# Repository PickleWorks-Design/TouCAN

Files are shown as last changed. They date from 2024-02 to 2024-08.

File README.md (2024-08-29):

# TouCAN
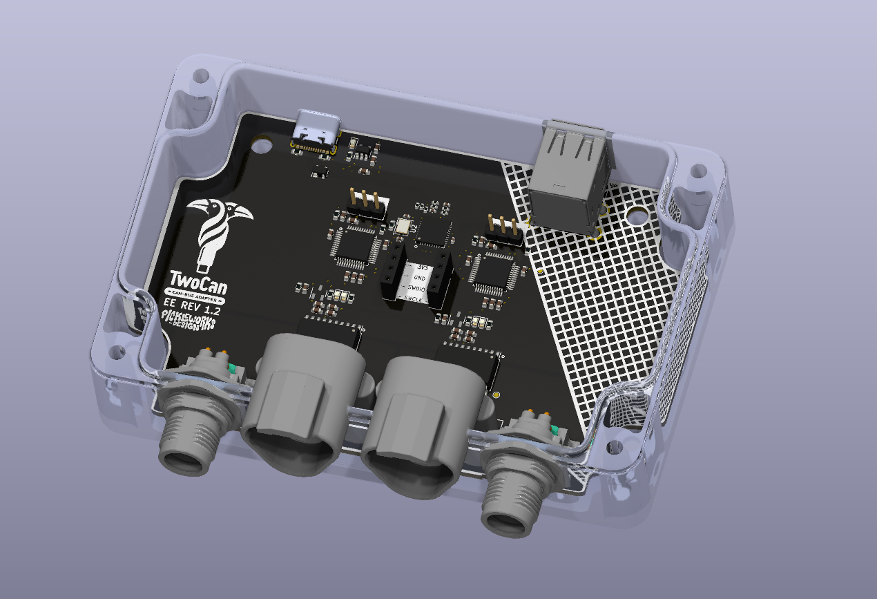
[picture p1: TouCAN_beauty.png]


Personal Project To integrate 2 Can Adapters in 1 board with Deutch DT 3pin connectors and an onboard usb HUB

USB to Can Adapter

This Project is Based on the CANAble USB to Canbus adapter project https://github.com/makerbase-mks/CANable-MKS/tree/main/Hardware/MKS%20CANable%20V2.0

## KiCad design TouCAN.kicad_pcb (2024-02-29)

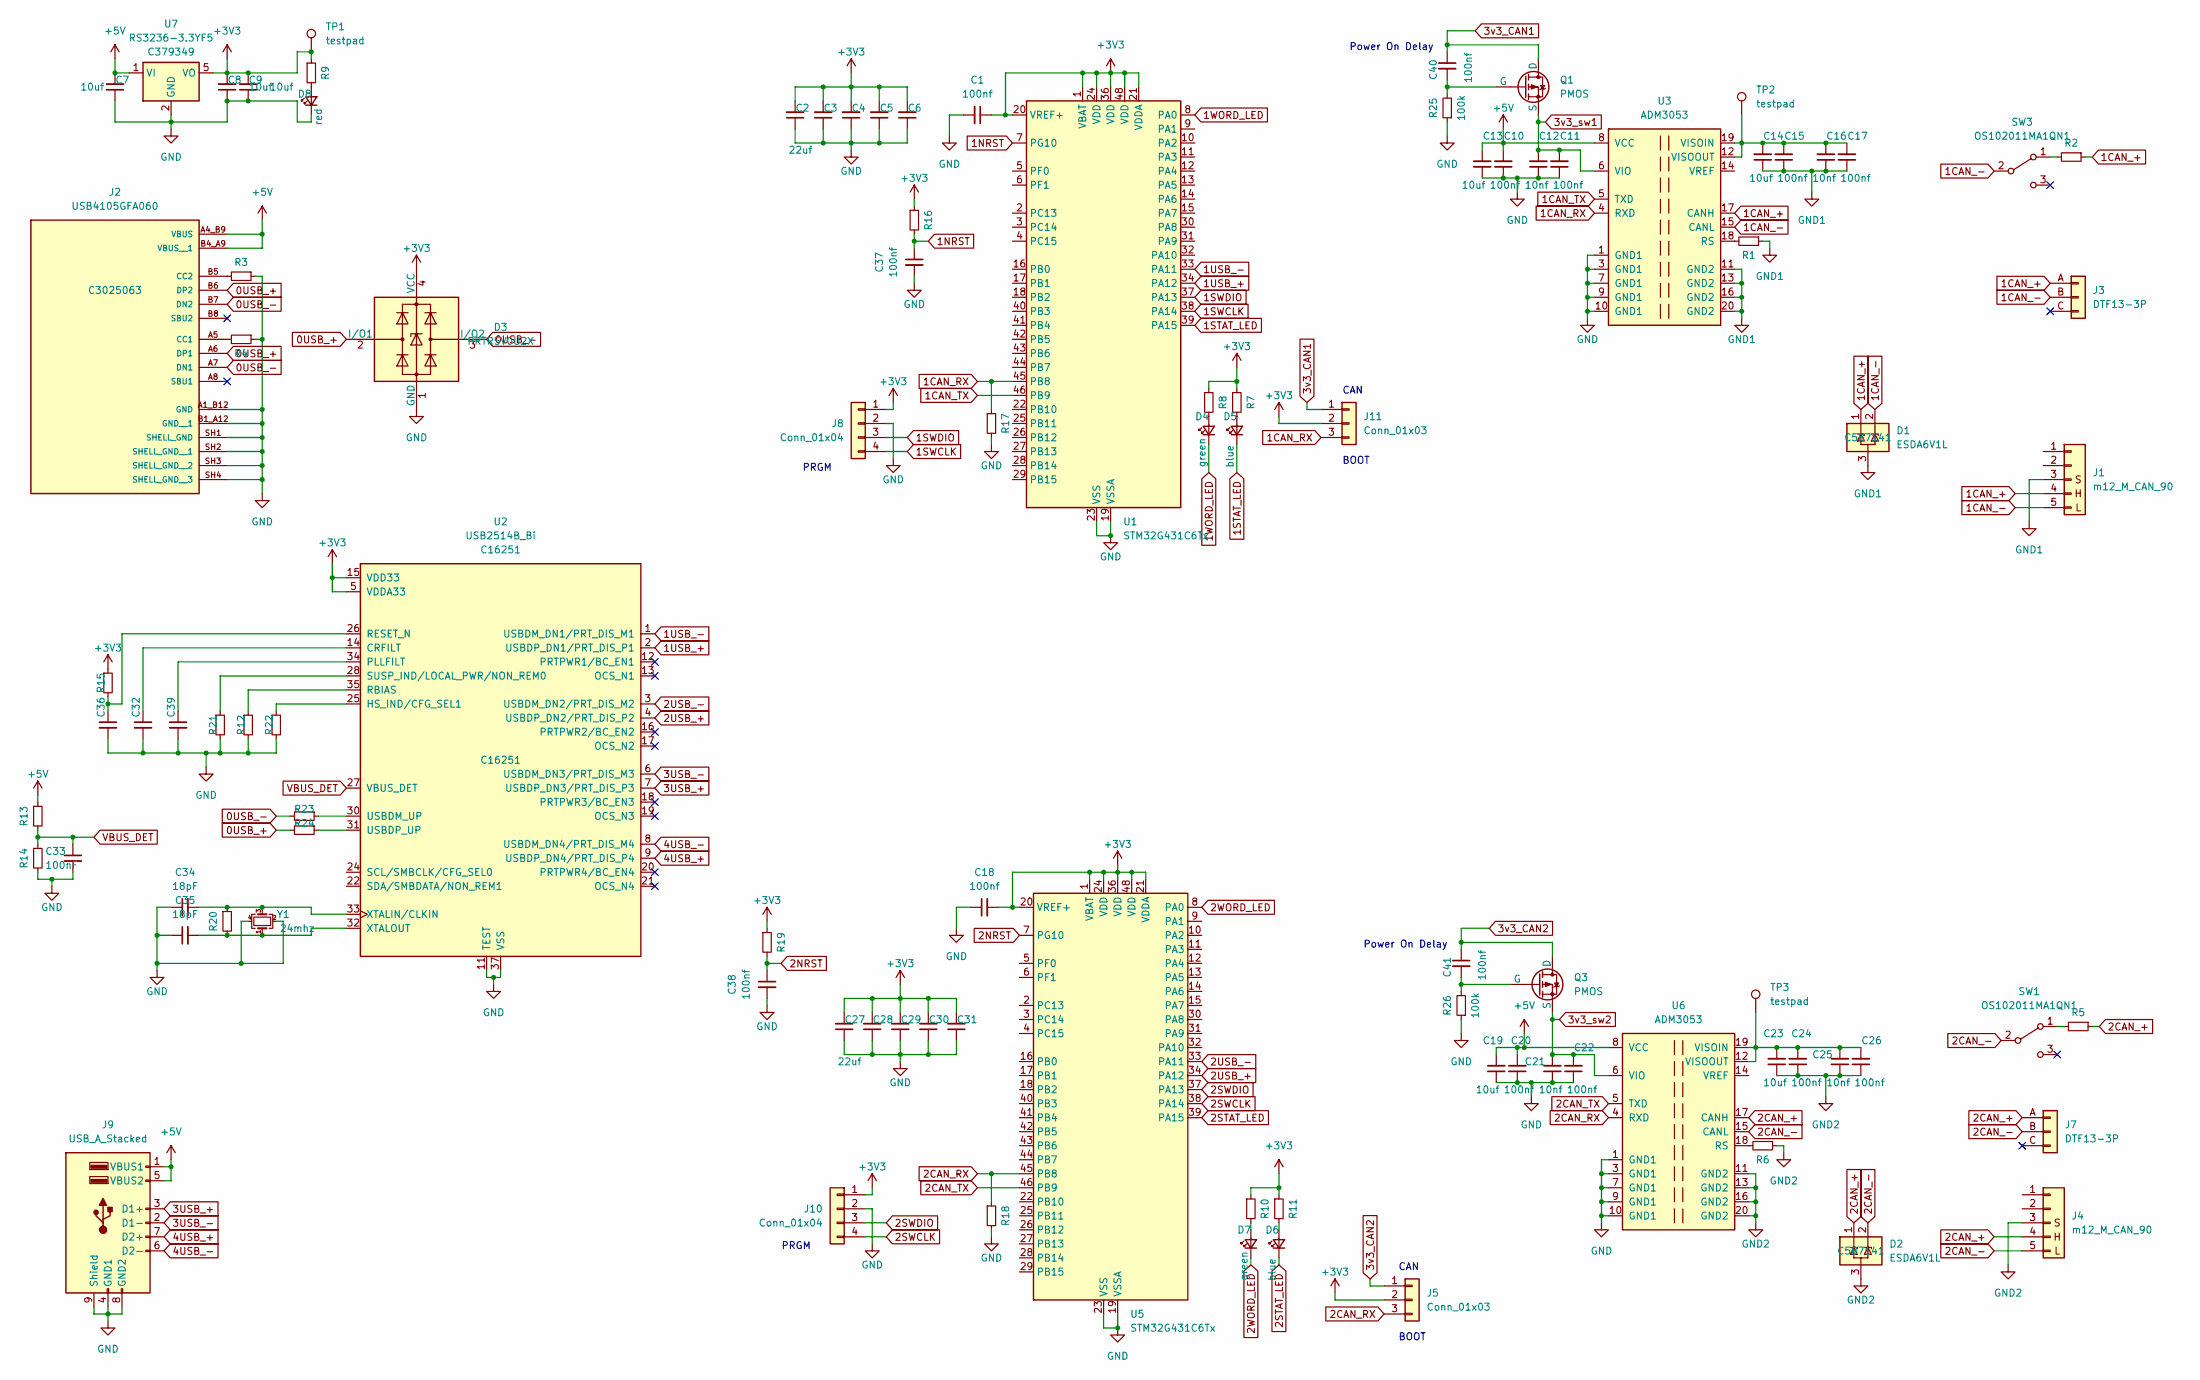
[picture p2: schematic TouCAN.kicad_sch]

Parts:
C1, C10, C11, C15, C17, C18, C20, C22, C24, C26, C37, C38, C40, C41: 100nf; C_0603_1608Metric; LCSC C14663
C2, C3, C4, C5, C6, C27, C28, C29, C30, C31: 22uf; C_0603_1608Metric; LCSC C59461
C7, C8, C9, C13, C14, C19, C23: 10uf; C_0603_1608Metric; LCSC C96446
C12, C16, C21, C25: 10nf; C_0603_1608Metric; LCSC C57112
C32, C33, C36, C39: 100nF; C_0402_1005Metric; LCSC C1525
C34, C35: 18pF; C_0402_1005Metric; LCSC C1549
D1, D2: ESDA6V1L; SOT-23-3; LCSC C587141
D3: PRTR5V0U2X; SOT-143; LCSC C2827688
D4, D7: green; LED_0603_1608Metric; LCSC C72043
D5, D6: blue; LED_0603_1608Metric; LCSC C72041
D8: red; LED_0603_1608Metric; LCSC C72044
J1, J4: m12_M_CAN_90; M12A-05PMMR-EE0001
J2: USB4105GFA060; GCT_USB4105GFA060; PARTREV B3; LCSC C3025063
J3, J7: DTF13-3P
J5, J11: Conn_01x03; PinHeader_1x03_P2.54mm_Vertical
J8, J10: Conn_01x04; PinSocket_1x04_P2.54mm_Vertical; LCSC C2691448
J9: USB_A_Stacked; USB_A_CUI_UJ2-ADH-TH_Horizontal_Stacked
Q1, Q3: PMOS; PMV48XP
R1, R6: 10r; R_0603_1608Metric; LCSC C22859
R2, R5: 120r; R_0603_1608Metric; LCSC C22787
R3, R4: 5.1k; R_0603_1608Metric; LCSC C23186
R7, R8, R9, R10, R11: 1k; R_0603_1608Metric; LCSC C21190
R12: 12k; R_0402_1005Metric; LCSC C25752
R13, R14, R15, R21, R22: 100k; R_0402_1005Metric; LCSC C25741
R16, R17, R18, R19: 10k; R_0603_1608Metric; LCSC C25804
R20: 1M; R_0603_1608Metric; LCSC C3152128
R23, R24: 0R; R_0402_1005Metric; LCSC C25086
R25, R26: 100k; R_0603_1608Metric; LCSC C25803
SW1, SW3: OS102011MA1QN1; LCSC C226259
TP1, TP2, TP3: testpad; TestPoint_Pad_D1.0mm
U1, U5: STM32G431C6Tx; LQFP-48_7x7mm_P0.5mm; LCSC C730096
U2: USB2514B_Bi; QFN-36-1EP_6x6mm_P0.5mm_EP3.7x3.7mm; LCSC C16251
U3, U6: ADM3053; SOIC-20W_7.5x12.8mm_P1.27mm; LCSC C117821
U7: RS3236-3.3YF5; SOT-23-5; LCSC C379349
Y1: 24mhz; Crystal_SMD_3225-4Pin_3.2x2.5mm; LCSC C362370

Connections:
0USB_+: D3.2 (I/O1), J2.A6 (DP1), J2.B6 (DP2), R24.2
0USB_-: D3.3 (I/O2), J2.A7 (DN1), J2.B7 (DN2), R23.2
1CAN_+: D1.1 (IO1), J1.4, J3.A (Pin_1), R2.1, U3.17 (CANH)
1CAN_-: D1.2 (IO2), J1.5, J3.B (Pin_2), SW3.2 (B), U3.15 (CANL)
1CAN_RX: J11.3, R17.1, U1.45 (PB8), U3.4 (RXD)
1CAN_TX: U1.46 (PB9), U3.5 (TXD)
1NRST: C37.1, R16.2, U1.7 (PG10)
1STAT_LED: D5.1 (K), U1.39 (PA15)
1SWCLK: J8.4, U1.38 (PA14)
1SWDIO: J8.3, U1.37 (PA13)
1USB_+: U1.34 (PA12), U2.2 (USBDP_DN1/PRT_DIS_P1)
1USB_-: U1.33 (PA11), U2.1 (USBDM_DN1/PRT_DIS_M1)
1WORD_LED: D4.1 (K), U1.8 (PA0)
2CAN_+: D2.1 (IO1), J4.4, J7.A (Pin_1), R5.1, U6.17 (CANH)
2CAN_-: D2.2 (IO2), J4.5, J7.B (Pin_2), SW1.2 (B), U6.15 (CANL)
2CAN_RX: J5.3, R18.1, U5.45 (PB8), U6.4 (RXD)
2CAN_TX: U5.46 (PB9), U6.5 (TXD)
2NRST: C38.1, R19.2, U5.7 (PG10)
2STAT_LED: D6.1 (K), U5.39 (PA15)
2SWCLK: J10.4, U5.38 (PA14)
2SWDIO: J10.3, U5.37 (PA13)
2USB_+: U2.4 (USBDP_DN2/PRT_DIS_P2), U5.34 (PA12)
2USB_-: U2.3 (USBDM_DN2/PRT_DIS_M2), U5.33 (PA11)
2WORD_LED: D7.1 (K), U5.8 (PA0)
3USB_+: J9.3 (D1+), U2.7 (USBDP_DN3/PRT_DIS_P3)
3USB_-: J9.2 (D1-), U2.6 (USBDM_DN3/PRT_DIS_M3)
3v3_CAN1: C40.1, J11.1, Q1.1 (D)
3v3_CAN2: C41.1, J5.1, Q3.1 (D)
3v3_sw1: C11.2, C12.2, Q1.3 (S), U3.6 (VIO)
3v3_sw2: C21.2, C22.2, Q3.3 (S), U6.6 (VIO)
4USB_+: J9.7 (D2+), U2.9 (USBDP_DN4/PRT_DIS_P4)
4USB_-: J9.6 (D2-), U2.8 (USBDM_DN4/PRT_DIS_M4)
+3V3: C1.1, C2.2, C3.2, C4.2, C5.2, C6.2, C8.2, C9.2, C18.2, C27.2, C28.2, C29.2, C30.2, C31.2, D3.4 (VCC), J5.2, J8.1, J10.1, J11.2, R7.1, R8.1, R9.1, R10.1, R11.1, R15.1, R16.1, R19.1, TP1.1, U1.1 (VBAT), U1.20 (VREF+), U1.21 (VDDA), U1.24 (VDD), U1.36 (VDD), U1.48 (VDD), U2.5 (VDDA33), U2.10 (VDDA33), U2.15 (VDD33), U2.23 (VDD33), U2.29 (VDDA33), U2.36 (VDDA33), U5.1 (VBAT), U5.20 (VREF+), U5.21 (VDDA), U5.24 (VDD), U5.36 (VDD), U5.48 (VDD), U7.5 (VO)
+5V: C7.2, C10.2, C13.2, C19.2, C20.2, J2.A4_B9 (VBUS), J2.B4_A9 (VBUS__1), J9.1 (VBUS1), J9.5 (VBUS2), R13.1, U3.8 (VCC), U6.8 (VCC), U7.1 (VI)
GND: C1.2, C2.1, C3.1, C4.1, C5.1, C6.1, C7.1, C8.1, C9.1, C10.1, C11.1, C12.1, C13.1, C18.1, C19.1, C20.1, C21.1, C22.1, C27.1, C28.1, C29.1, C30.1, C31.1, C32.2, C33.2, C34.1, C35.1, C36.2, C37.2, C38.2, C39.2, D3.1 (GND), D8.1 (K), J2.A1_B12 (GND), J2.B1_A12 (GND__1), J2.SH1 (SHELL_GND), J2.SH2 (SHELL_GND__1), J2.SH3 (SHELL_GND__2), J2.SH4 (SHELL_GND__3), J8.2, J9.4 (GND1), J9.8 (GND2), J9.9 (Shield), J10.2, R3.1, R4.1, R12.2, R14.2, R17.2, R18.2, R21.2, R22.2, R25.1, R26.1, U1.19 (VSSA), U1.23 (VSS), U1.35 (VSS), U1.47 (VSS), U2.11 (TEST), U2.37 (VSS), U3.1 (GND1), U3.3 (GND1), U3.7 (GND1), U3.9 (GND1), U3.10 (GND1), U5.19 (VSSA), U5.23 (VSS), U5.35 (VSS), U5.47 (VSS), U6.1 (GND1), U6.3 (GND1), U6.7 (GND1), U6.9 (GND1), U6.10 (GND1), U7.2 (GND), Y1.2, Y1.4
GND1: C14.1, C15.1, C16.1, C17.1, D1.3 (GND), J1.3, R1.1, U3.11 (GND2), U3.13 (GND2), U3.16 (GND2), U3.20 (GND2)
GND2: C23.1, C24.1, C25.1, C26.1, D2.3 (GND), J4.3, R6.1, U6.11 (GND2), U6.13 (GND2), U6.16 (GND2), U6.20 (GND2)
unnamed: D4.2 (A), R8.2
unnamed: D5.2 (A), R7.2
unnamed: D6.2 (A), R11.2
unnamed: D7.2 (A), R10.2
unnamed: D8.2 (A), R9.2
unnamed: J2.A5 (CC1), R4.2
unnamed: J2.B5 (CC2), R3.2
unnamed: C40.2, Q1.2 (G), R25.2
unnamed: C41.2, Q3.2 (G), R26.2
unnamed: R5.2, SW1.1 (A)
unnamed: R2.2, SW3.1 (A)
unnamed: C32.1, U2.14 (CRFILT)
unnamed: R22.1, U2.25 (HS_IND/CFG_SEL1)
unnamed: C39.1, U2.34 (PLLFILT)
unnamed: R12.1, U2.35 (RBIAS)
unnamed: C36.1, R15.2, U2.26 (RESET_N)
unnamed: R21.1, U2.28 (SUSP_IND/LOCAL_PWR/NON_REM0)
unnamed: R23.1, U2.30 (USBDM_UP)
unnamed: R24.1, U2.31 (USBDP_UP)
unnamed: C34.2, R20.1, U2.33 (XTALIN/CLKIN), Y1.3
unnamed: C35.2, R20.2, U2.32 (XTALOUT), Y1.1
unnamed: R1.2, U3.18 (RS)
unnamed: C14.2, C15.2, C16.2, C17.2, TP2.1, U3.12 (VISOOUT), U3.19 (VISOIN)
unnamed: R6.2, U6.18 (RS)
unnamed: C23.2, C24.2, C25.2, C26.2, TP3.1, U6.12 (VISOOUT), U6.19 (VISOIN)
VBUS_DET: C33.1, R13.2, R14.1, U2.27 (VBUS_DET)

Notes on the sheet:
Power On Delay
BOOT
CAN
PRGM

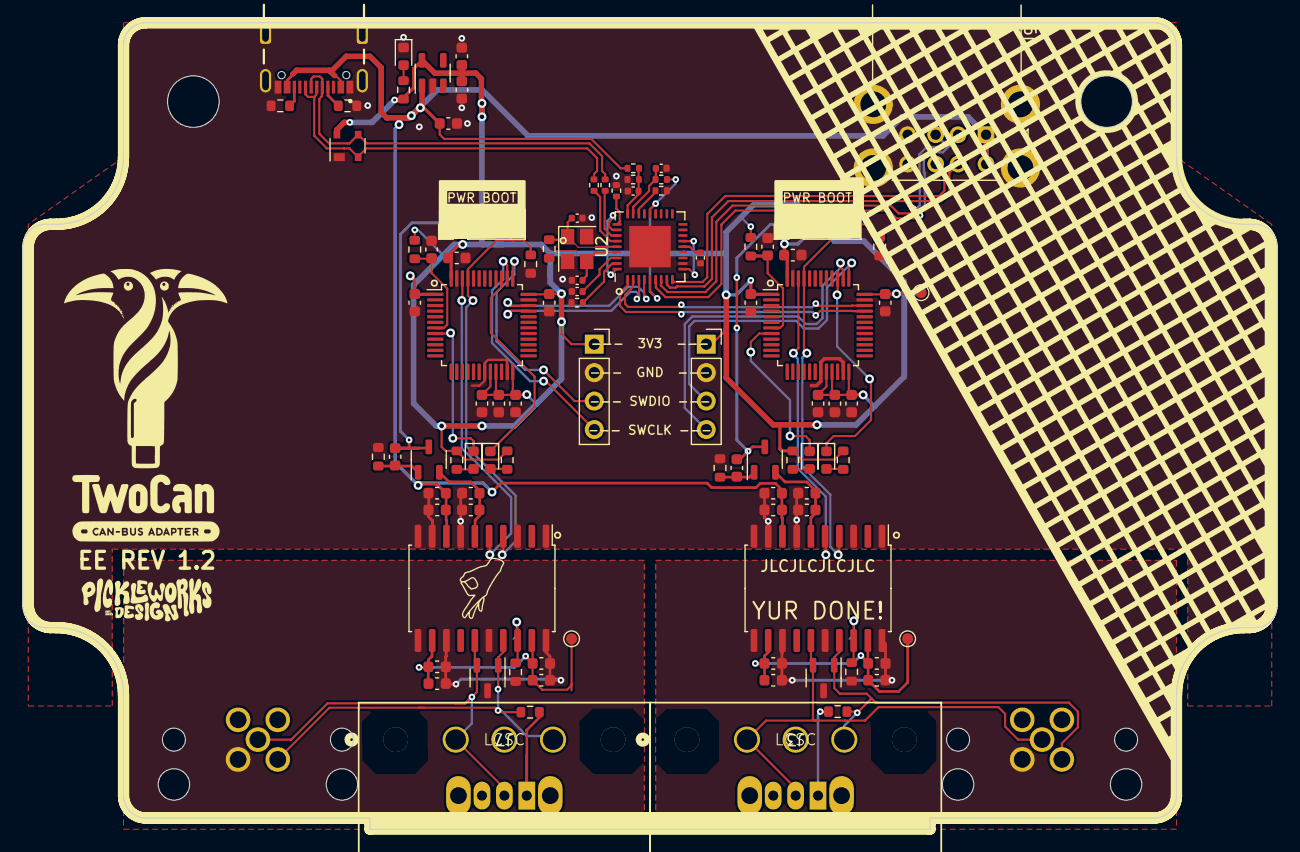
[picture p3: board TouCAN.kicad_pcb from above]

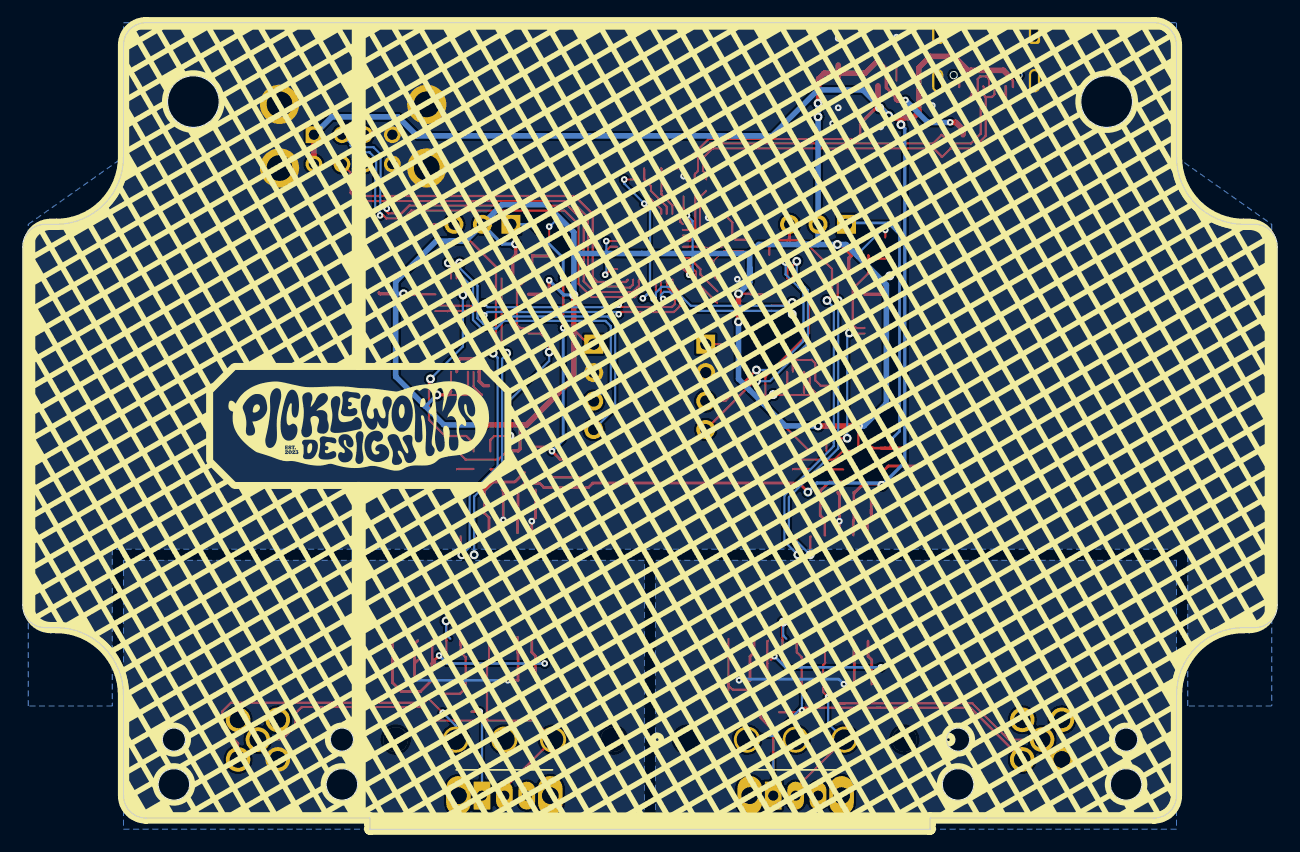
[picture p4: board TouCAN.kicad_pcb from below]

Board: 2 copper layers, 112.0 x 72.0 mm, 99 parts (2 on the bottom side), 63 nets.
